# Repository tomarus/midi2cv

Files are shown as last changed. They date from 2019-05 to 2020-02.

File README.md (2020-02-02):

MIARPH * MIDI2CV + ARPEGGIATOR
==============================

Miarph is an Arduino based MIDI2CV converter with 4 0-5V 12 bit DAC's and 10 trigger outputs.

Preview 1.0 PCB

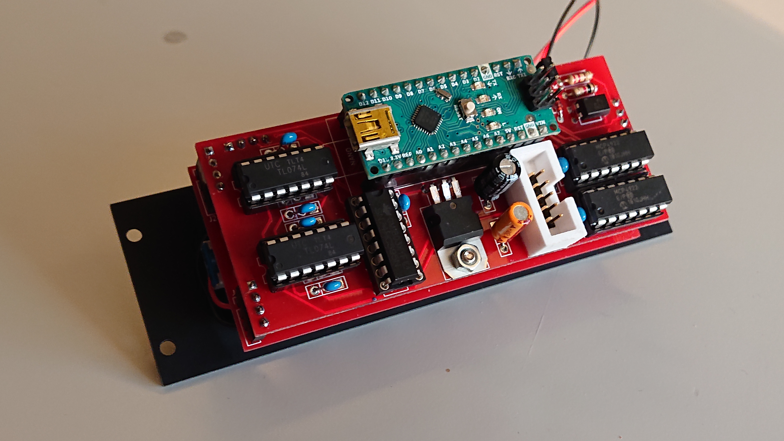
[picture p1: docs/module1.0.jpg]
Preview 1.0 Module


Video Demo (http://www.youtube.com/watch?v=SEof3n9Ys9w)

Video Demo (http://www.youtube.com/watch?v=0akh9hcQQY0)

## Features

* 4 individual 0-5v 12 bit DAC's (MCP4922 based)
* 10 Trigger outputs
* Dual Arpeggiator
* SYSEX configurable.
* Two MIDI-CC controller outputs.
* Two Midi Note + Trigger outputs.
* Split note (single channel) or two individual channel operations.
* 8 individually programmable gate triggers to be either drum trigger or clock divider.

## Building Notes

* Use a real Arduino Nano or atleast one with a real FTDI chip.
* There is no tuning possibility, but a stable LM7805 is key.
* The LED is on the wrong side but easy fixable using 2 short wires. (This is the only mistake on the PCB).
* The LED resistor is dependent on your LED specs.
* Capacitors have three holes, always use the square one and one of the others. Both 2.54mm and 5.08mm caps will fit.
* Polarized caps should have their positive in the square hole and the negative pointing outwards the board. (See image above!)
* Remove the jumper and power cable before programming!
* DO NOT CONNECT POWER AND USB AT THE SAME TIME!

## BUGS

* It crashes at split note change. But after a reset it is correctly read from eeprom.
* Transpose is buggy, but required because it can only support 60 MIDI notes.

## Programming Using Webconfig

See https://midi.tomarus.io/miarph/

You need a modern browser like Opera or Chrome to use this site.

Note that all values are initially *unknown* until you actually change something.
The device has no MIDI output so config values can't be read back.

After initially building the device, you should set all of your defaults once via webconfig.
After changing values it is stored on the device's eeprom and used at the next power up.

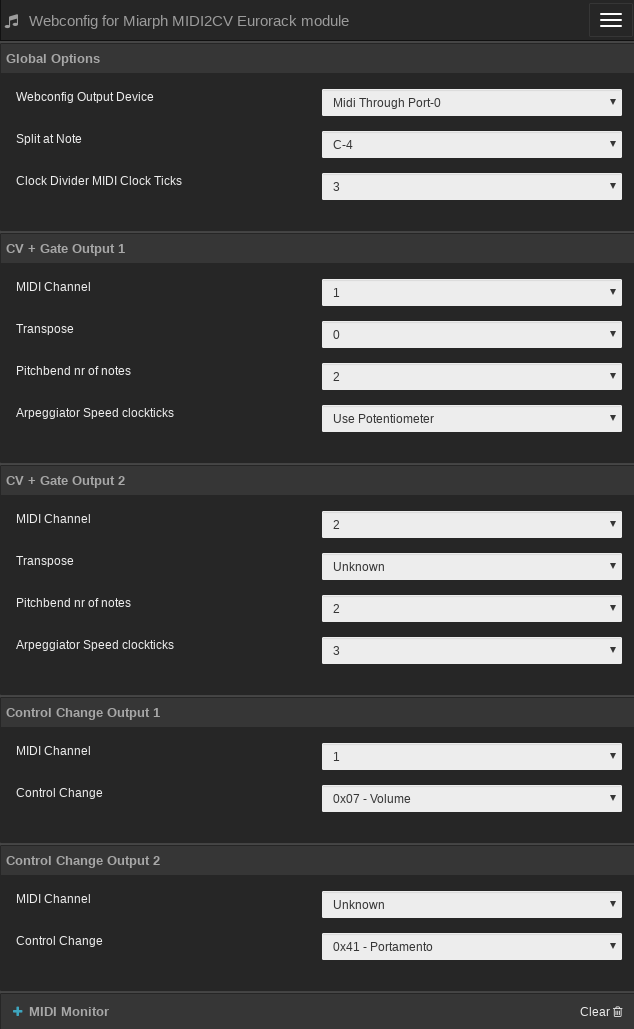
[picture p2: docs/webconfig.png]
Webconfig Screenshot


## Programming Using the Commandline

Use the ```midi2cv``` Go utility to program the device.

Example:

```./midi2cv write 0x01 0x77```

Where ```0x01``` is the address and ```0x77``` the value.

List of addresses to program:

| Address | Description | Example value |
| -- | -- | -- |
| 0x00 | unused | -- |
| 0x01 | Split keyboard at note | 0x40 (use 0x00 for no split) |
| 0x02 | MIDI 1 Channel | 0x01 |
| 0x03 | MIDI 2 Channel | 0x02 |
| 0x04 | Transpose Channel 1 | 0x40 |
| 0x05 | Transpose Channel 2 | 0x40 |
| 0x06 | Control Change Number Channel 1 | 0x07 (0x07 = volume) |
| 0x07 | Control Change Number Channel 2 | 0x6A (0x6A = filter cutoff) |
| 0x08 | Control Change Channel 1 | 0x01 |
| 0x09 | Control Change Channel 2 | 0x02 |
| 0x0a | Pitchbend Channel 1 | 0x02 (number of notes) |
| 0x0b | Pitchbend Channel 2 | 0x0c (number of notes) |
| 0x0c | Midi Channel 1 sync | 0x00 (00 = use potmeter, otherwise nr of midi clock ticks) |
| 0x0d | Midi Channel 2 sync | 0x00 (00 = use potmeter, otherwise nr of midi clock ticks) |
| 0x0e | Clockticks to advance the clock divider | 0x03 (0x03 = sync to quarter notes) |
| 0x0f | unused | -- |
| 0x10..0x18 | Port Mode (0 = clock divider, 1 = drum trigger) | 0x00 |
| 0x18..0x20 | Port Trigger Note | 0x36 |
| 0x20..0x28 | Port Clock Divider Division (0=1/1, 1=1/2, 2=1/4, 3=1/8, etc) | 0x00 |

## Bill Of Materials

|Designator                   |Package                                 |Quantity|Designation |PartNo|
|-----------------------------|----------------------------------------|--------|------------|------|
|RV1                          |Potentiometer_Alps_RK09K_Single_Vertical|1       |B10K        | |
|NANO                         |Arduino_Nano_Silk                       |1       |Nano v3     | |
|C1                           |GenericCap                              |1       |100uF       | |
|C2                           |GenericCap                              |1       |10uF        | |
|C3,C4,C5,C6,C7,C8,C9         |GenericCap                              |7       |100nF       | |
|D1                           |LED_D3.0mm                              |1       |LED         | |
|D2,D3,D4                     |D_DO-35_SOD27_P7.62mm_Horizontal        |3       |D           | |
|J1                           |PinHeader_1x02_P2.54mm_Vertical         |1       |ProgramJmpr | |
|J2                           |IDC-Header_2x05_P2.54mm_Vertical        |1       |Power       | |
|J3,J14,J15                   |PinSocket_1x04_P2.54mm_Vertical         |3       |Conn_01x04_M| |
|J4,J24,J25                   |PinHeader_1x04_P2.54mm_Vertical         |3       |Conn_01x04_F| |
|J5                           |PinSocket_1x08_P2.54mm_Vertical         |1       |Conn_01x08_M| |
|J6                           |PinHeader_1x08_P2.54mm_Vertical         |1       |Conn_01x08_F| |
|J7                           |Jack_3.5mm_QingPu_WQP-PJ366ST_Vertical  |1       |Midi Input  | |
|J8-J13,J16-J23               |Jack_3.5mm_QingPu_WQP-PJ398SM_Vertical  |14      |Misc        | |
|R1,R2                        |R_Axial_DIN0207_L6.3mm_D2.5mm_P7.62mm   |2       |2K2         | |
|R3,R4,R5,R6                  |R_Axial_DIN0207_L6.3mm_D2.5mm_P7.62mm   |4       |1K          | |
|R7                           |R_Axial_DIN0207_L6.3mm_D2.5mm_P7.62mm   |1       |220         | |
|R8,R9,R10,R11,R12,R13,R14,R15|R_Axial_DIN0207_L6.3mm_D2.5mm_P7.62mm   |8       |100         | |
|U1                           |TO-220-3_Horizontal_TabDown             |1       |L7805       | |
|U2                           |DIP-8_W7.62mm                           |1       |24LC256     | |
|U5                           |DIP-4_W7.62mm                           |1       |PC817       | PC817XNNSZ1B |
|U6,U8                        |DIP-14_W7.62mm                          |2       |TL074       | |
|U7                           |DIP-16_W7.62mm                          |1       |74HC595     | |
|U3,U4                        |DIP-14_W7.62mm                          |2       |MCP4922     | |

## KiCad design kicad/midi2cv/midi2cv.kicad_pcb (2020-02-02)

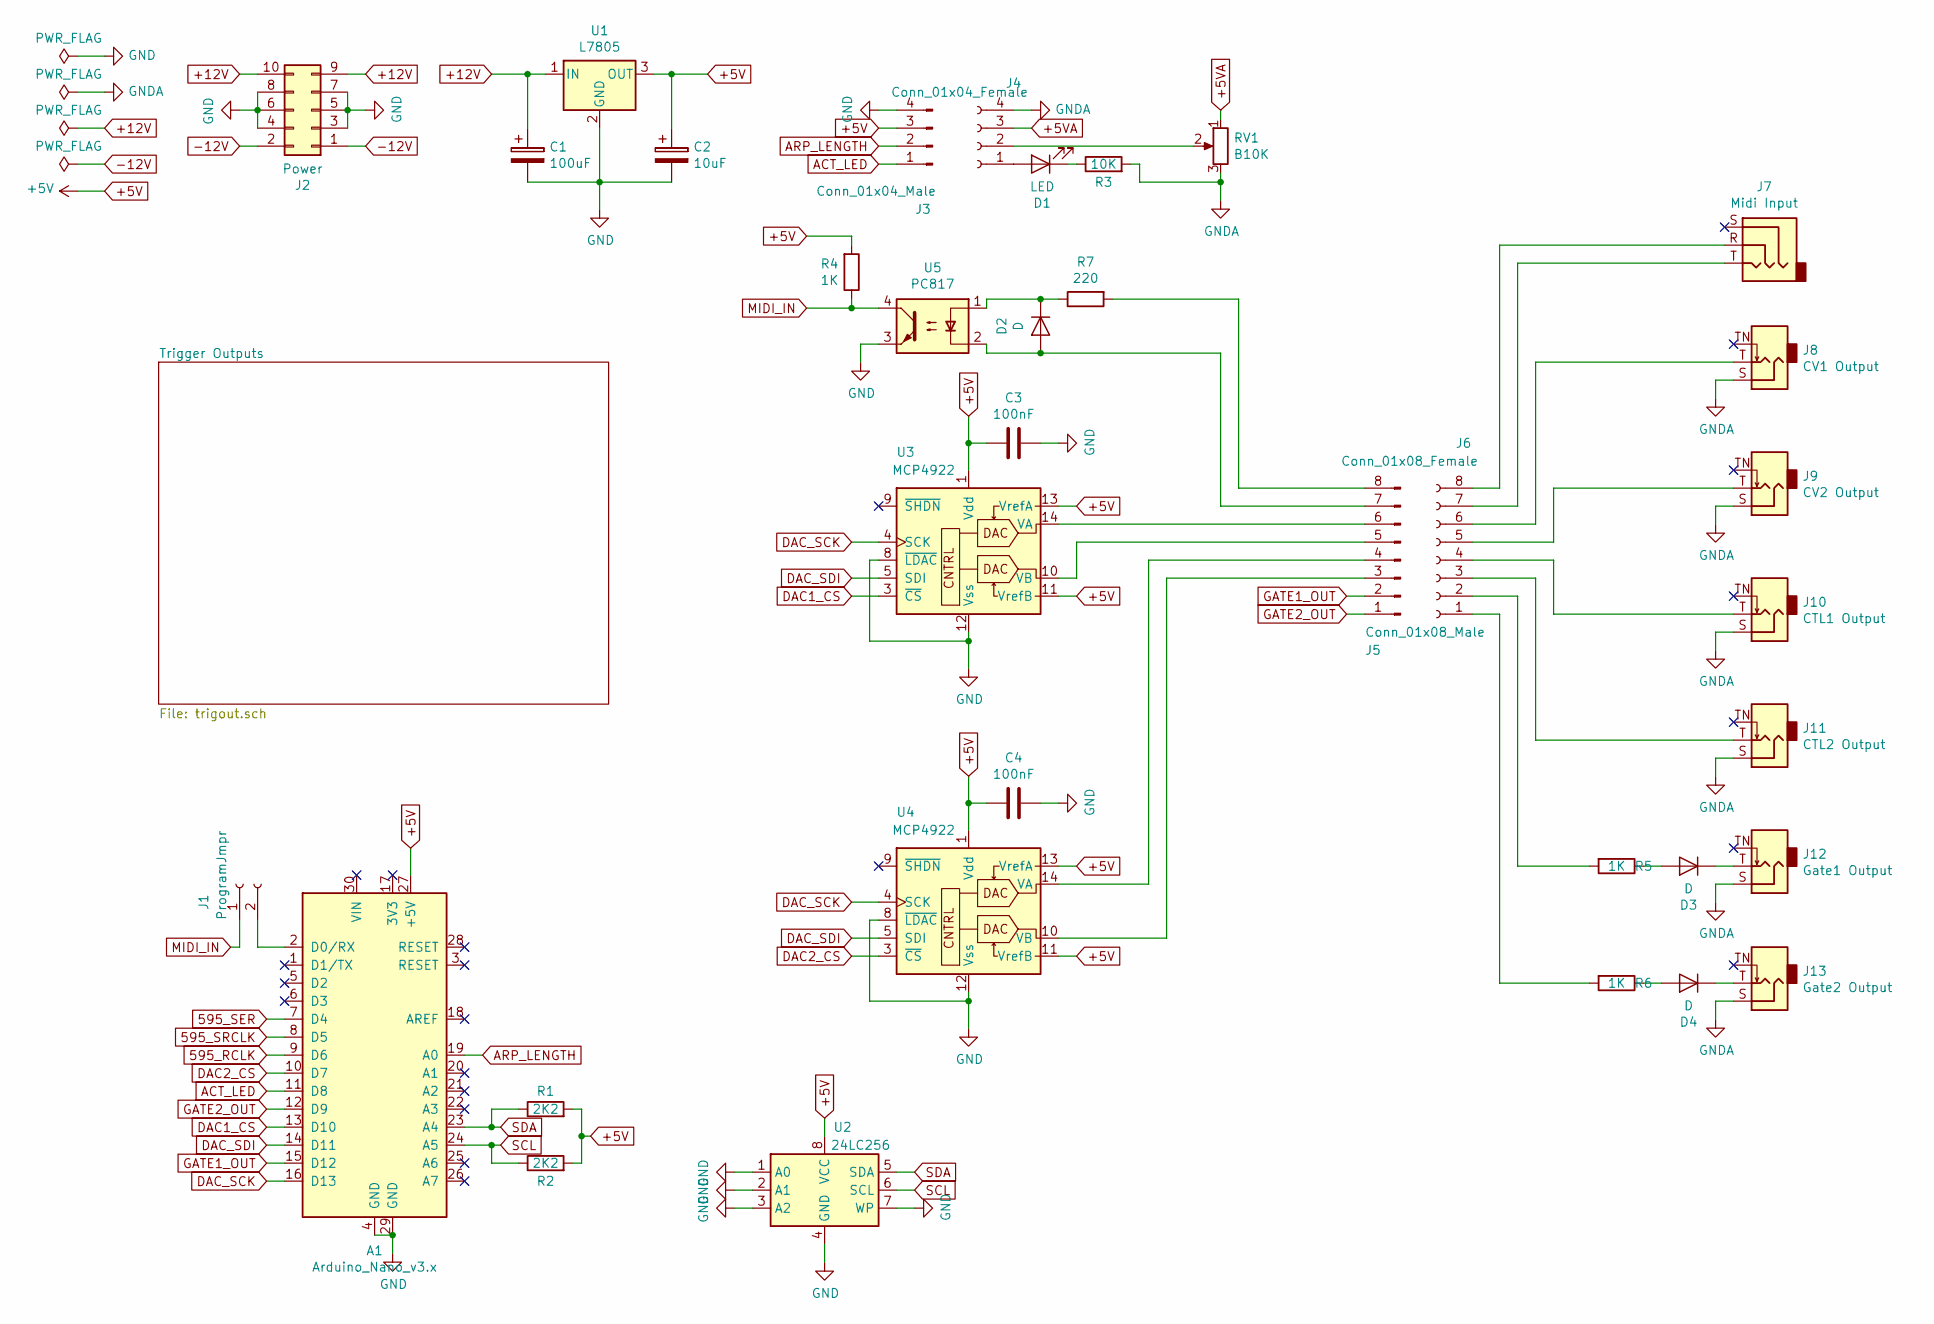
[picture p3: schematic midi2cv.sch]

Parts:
A1: Arduino_Nano_v3.x; Arduino_Nano_Silk
C1: 100uF; GenericCap
C2: 10uF; GenericCap
C3, C4: 100nF; GenericCap
D1: LED; LED_D3.0mm
D2, D3, D4: D; D_DO-35_SOD27_P7.62mm_Horizontal
J1: ProgramJmpr; PinHeader_1x02_P2.54mm_Vertical
J2: Power; IDC-Header_2x05_P2.54mm_Vertical
J3: Conn_01x04_Male; PinSocket_1x04_P2.54mm_Vertical
J4: Conn_01x04_Female; PinHeader_1x04_P2.54mm_Vertical
J5: Conn_01x08_Male; PinSocket_1x08_P2.54mm_Vertical
J6: Conn_01x08_Female; PinHeader_1x08_P2.54mm_Vertical
J7: Midi Input; Jack_3.5mm_QingPu_WQP-PJ366ST_Vertical_CircularHoles
J8: CV1 Output; Jack_3.5mm_QingPu_WQP-PJ398SM_Vertical_CircularHoles
J9: CV2 Output; Jack_3.5mm_QingPu_WQP-PJ398SM_Vertical_CircularHoles
J10: CTL1 Output; Jack_3.5mm_QingPu_WQP-PJ398SM_Vertical_CircularHoles
J11: CTL2 Output; Jack_3.5mm_QingPu_WQP-PJ398SM_Vertical_CircularHoles
J12: Gate1 Output; Jack_3.5mm_QingPu_WQP-PJ398SM_Vertical_CircularHoles
J13: Gate2 Output; Jack_3.5mm_QingPu_WQP-PJ398SM_Vertical_CircularHoles
R1, R2: 2K2; R_Axial_DIN0207_L6.3mm_D2.5mm_P7.62mm_Horizontal
R3: 10K; R_Axial_DIN0207_L6.3mm_D2.5mm_P7.62mm_Horizontal
R4, R5, R6: 1K; R_Axial_DIN0207_L6.3mm_D2.5mm_P7.62mm_Horizontal
R7: 220; R_Axial_DIN0207_L6.3mm_D2.5mm_P7.62mm_Horizontal
RV1: B10K; Potentiometer_Alps_RK09K_Single_Vertical
U1: L7805; TO-220-3_Horizontal_TabDown
U2: 24LC256; DIP-8_W7.62mm
U3, U4: MCP4922; DIP-14_W7.62mm
U5: PC817; DIP-4_W7.62mm

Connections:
595_RCLK: A1.9 (D6); also elsewhere on the board
595_SER: A1.7 (D4); also elsewhere on the board
595_SRCLK: A1.8 (D5); also elsewhere on the board
+5V: A1.27 (+5V), C2.1, C3.1, C4.1, J3.3, R1.2, R2.2, R4.2, U1.3 (OUT), U2.8 (VCC), U3.1 (Vdd), U3.11 (VrefB), U3.13 (VrefA), U4.1 (Vdd), U4.11 (VrefB), U4.13 (VrefA); also elsewhere on the board
+5VA: J4.3, RV1.1
+12V: C1.1, J2.9, J2.10, U1.1 (IN); also elsewhere on the board
-12V: J2.1, J2.2; also elsewhere on the board
ACT_LED: A1.11 (D8), J3.1
ARP_LENGTH: A1.19 (A0), J3.2
DAC1_CS: A1.13 (D10), U3.3 (~CS)
DAC2_CS: A1.10 (D7), U4.3 (~CS)
DAC_SCK: A1.16 (D13), U3.4 (SCK), U4.4 (SCK)
DAC_SDI: A1.14 (D11), U3.5 (SDI), U4.5 (SDI)
GATE1_OUT: A1.15 (D12), J5.2
GATE2_OUT: A1.12 (D9), J5.1
GND: A1.4 (GND), A1.29 (GND), C1.2, C2.2, C3.2, C4.2, J2.3, J2.4, J2.5, J2.6, J2.7, J2.8, J3.4, U1.2 (GND), U2.1 (A0), U2.2 (A1), U2.3 (A2), U2.4 (GND), U2.7 (WP), U3.8 (~LDAC), U3.12 (Vss), U4.8 (~LDAC), U4.12 (Vss), U5.3; also elsewhere on the board
GNDA: J4.4, J8.S, J9.S, J10.S, J11.S, J12.S, J13.S, R3.2, RV1.3; also elsewhere on the board
MIDI_IN: J1.1, R4.1, U5.4
unnamed: A1.2 (D0/RX), J1.2
unnamed: D1.1 (K), R3.1
unnamed: D1.2 (A), J4.1
unnamed: D2.1 (K), R7.1, U5.1
unnamed: D2.2 (A), J5.7, U5.2
unnamed: D3.1 (K), J12.T
unnamed: D3.2 (A), R5.1
unnamed: D4.1 (K), J13.T
unnamed: D4.2 (A), R6.1
unnamed: J4.2, RV1.2
unnamed: J5.3, U4.10 (VB)
unnamed: J5.4, U4.14 (VA)
unnamed: J5.5, U3.10 (VB)
unnamed: J5.6, U3.14 (VA)
unnamed: J5.8, R7.2
unnamed: J6.1, R6.2
unnamed: J6.2, R5.2
unnamed: J6.5, J9.T
unnamed: J6.6, J8.T
unnamed: J6.7, J7.T
unnamed: J6.8, J7.R
unnamed: J6.4, J10.T
unnamed: J6.3, J11.T
SCL: A1.24 (A5), R2.1, U2.6 (SCL)
SDA: A1.23 (A4), R1.1, U2.5 (SDA)

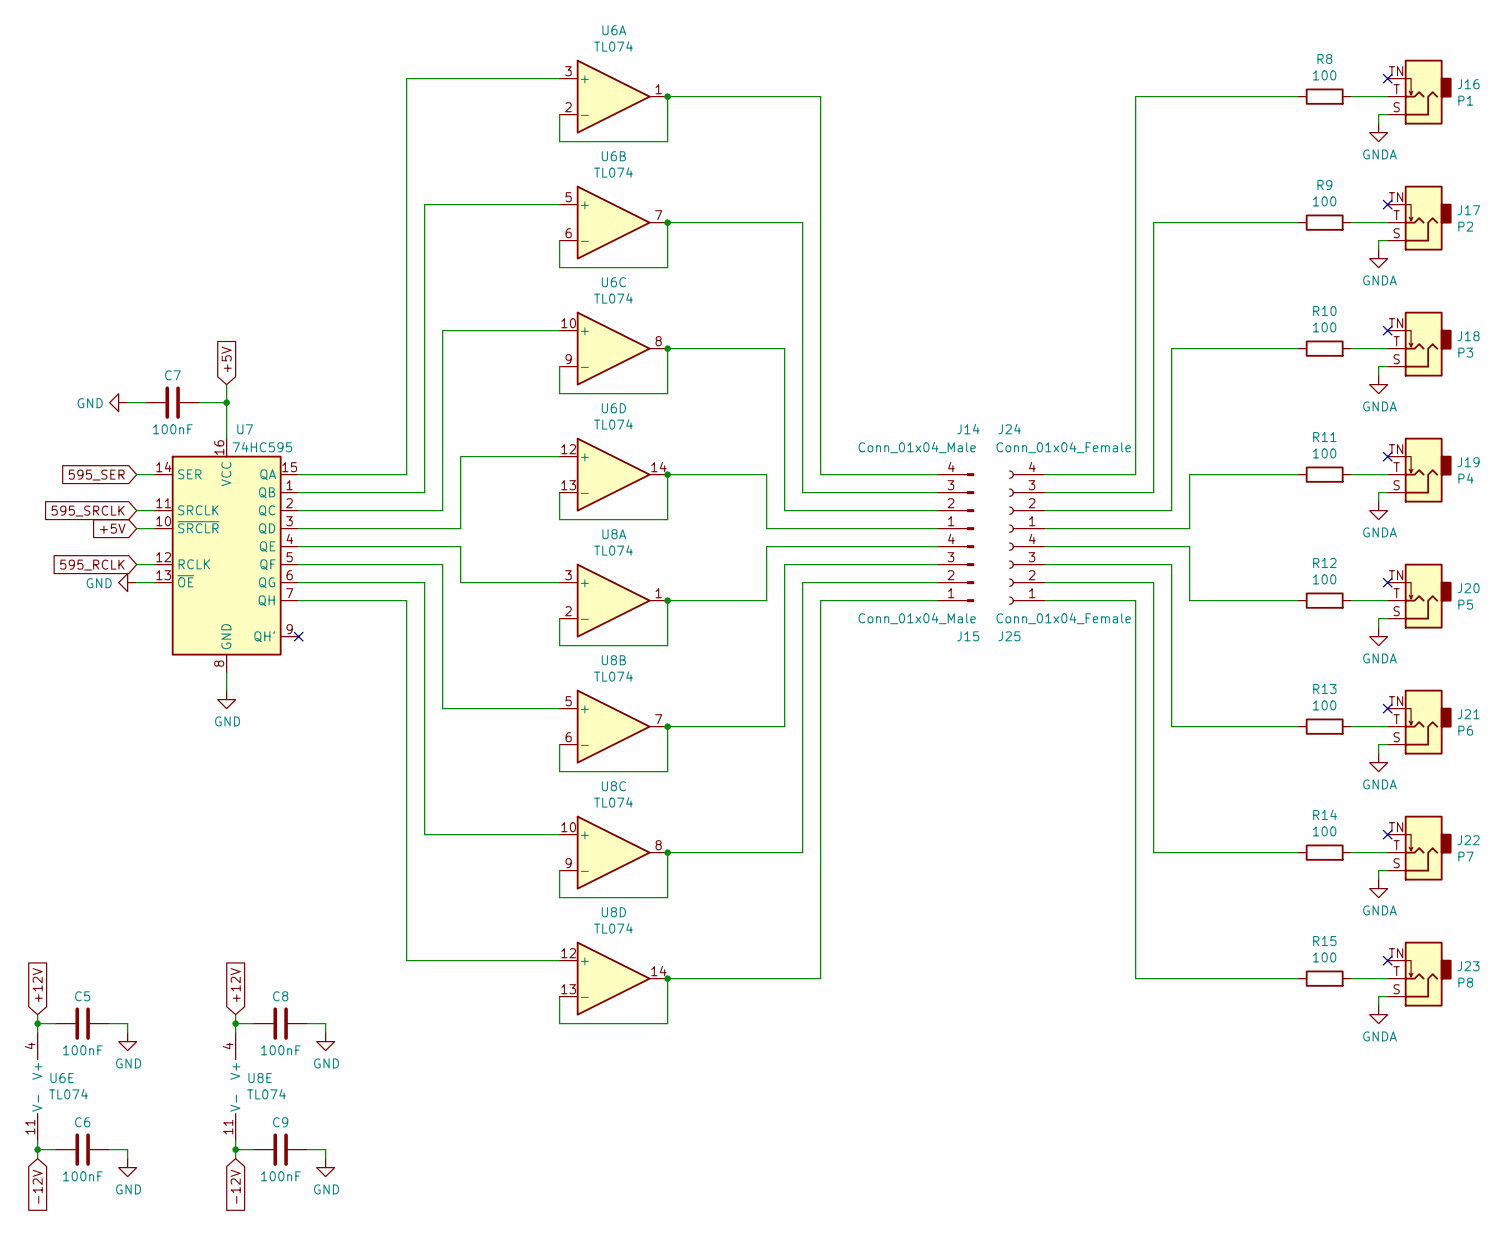
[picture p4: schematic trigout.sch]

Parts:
C5, C6, C7, C8, C9: 100nF; GenericCap
J14, J15: Conn_01x04_Male; PinSocket_1x04_P2.54mm_Vertical
J16: P1; Jack_3.5mm_QingPu_WQP-PJ398SM_Vertical_CircularHoles
J17: P2; Jack_3.5mm_QingPu_WQP-PJ398SM_Vertical_CircularHoles
J18: P3; Jack_3.5mm_QingPu_WQP-PJ398SM_Vertical_CircularHoles
J19: P4; Jack_3.5mm_QingPu_WQP-PJ398SM_Vertical_CircularHoles
J20: P5; Jack_3.5mm_QingPu_WQP-PJ398SM_Vertical_CircularHoles
J21: P6; Jack_3.5mm_QingPu_WQP-PJ398SM_Vertical_CircularHoles
J22: P7; Jack_3.5mm_QingPu_WQP-PJ398SM_Vertical_CircularHoles
J23: P8; Jack_3.5mm_QingPu_WQP-PJ398SM_Vertical_CircularHoles
J24, J25: Conn_01x04_Female; PinHeader_1x04_P2.54mm_Vertical
R8, R9, R10, R11, R12, R13, R14, R15: 100; R_Axial_DIN0207_L6.3mm_D2.5mm_P7.62mm_Horizontal
U6, U8: TL074; DIP-14_W7.62mm
U7: 74HC595; DIP-16_W7.62mm

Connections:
595_RCLK: U7.12 (RCLK); also elsewhere on the board
595_SER: U7.14 (SER); also elsewhere on the board
595_SRCLK: U7.11 (SRCLK); also elsewhere on the board
+5V: C7.1, U7.10 (~SRCLR), U7.16 (VCC); also elsewhere on the board
+12V: C5.2, C8.2, U6.4 (V+), U8.4 (V+); also elsewhere on the board
-12V: C6.2, C9.2, U6.11 (V-), U8.11 (V-); also elsewhere on the board
GND: C5.1, C6.1, C7.2, C8.1, C9.1, U7.8 (GND), U7.13 (~OE); also elsewhere on the board
GNDA: J16.S, J17.S, J18.S, J19.S, J20.S, J21.S, J22.S, J23.S; also elsewhere on the board
unnamed: J14.1, U6.13 (-), U6.14
unnamed: J14.2, U6.8, U6.9 (-)
unnamed: J14.3, U6.6 (-), U6.7
unnamed: J14.4, U6.1, U6.2 (-)
unnamed: J15.1, U8.13 (-), U8.14
unnamed: J15.2, U8.8, U8.9 (-)
unnamed: J15.3, U8.6 (-), U8.7
unnamed: J15.4, U8.1, U8.2 (-)
unnamed: J16.T, R8.2
unnamed: J17.T, R9.2
unnamed: J18.T, R10.2
unnamed: J19.T, R11.2
unnamed: J20.T, R12.2
unnamed: J21.T, R13.2
unnamed: J22.T, R14.2
unnamed: J23.T, R15.2
unnamed: J24.1, R11.1
unnamed: J24.2, R10.1
unnamed: J24.3, R9.1
unnamed: J24.4, R8.1
unnamed: J25.1, R15.1
unnamed: J25.2, R14.1
unnamed: J25.3, R13.1
unnamed: J25.4, R12.1
unnamed: U6.3 (+), U7.15 (QA)
unnamed: U6.5 (+), U7.1 (QB)
unnamed: U6.10 (+), U7.2 (QC)
unnamed: U6.12 (+), U7.3 (QD)
unnamed: U7.4 (QE), U8.3 (+)
unnamed: U7.5 (QF), U8.5 (+)
unnamed: U7.6 (QG), U8.10 (+)
unnamed: U7.7 (QH), U8.12 (+)

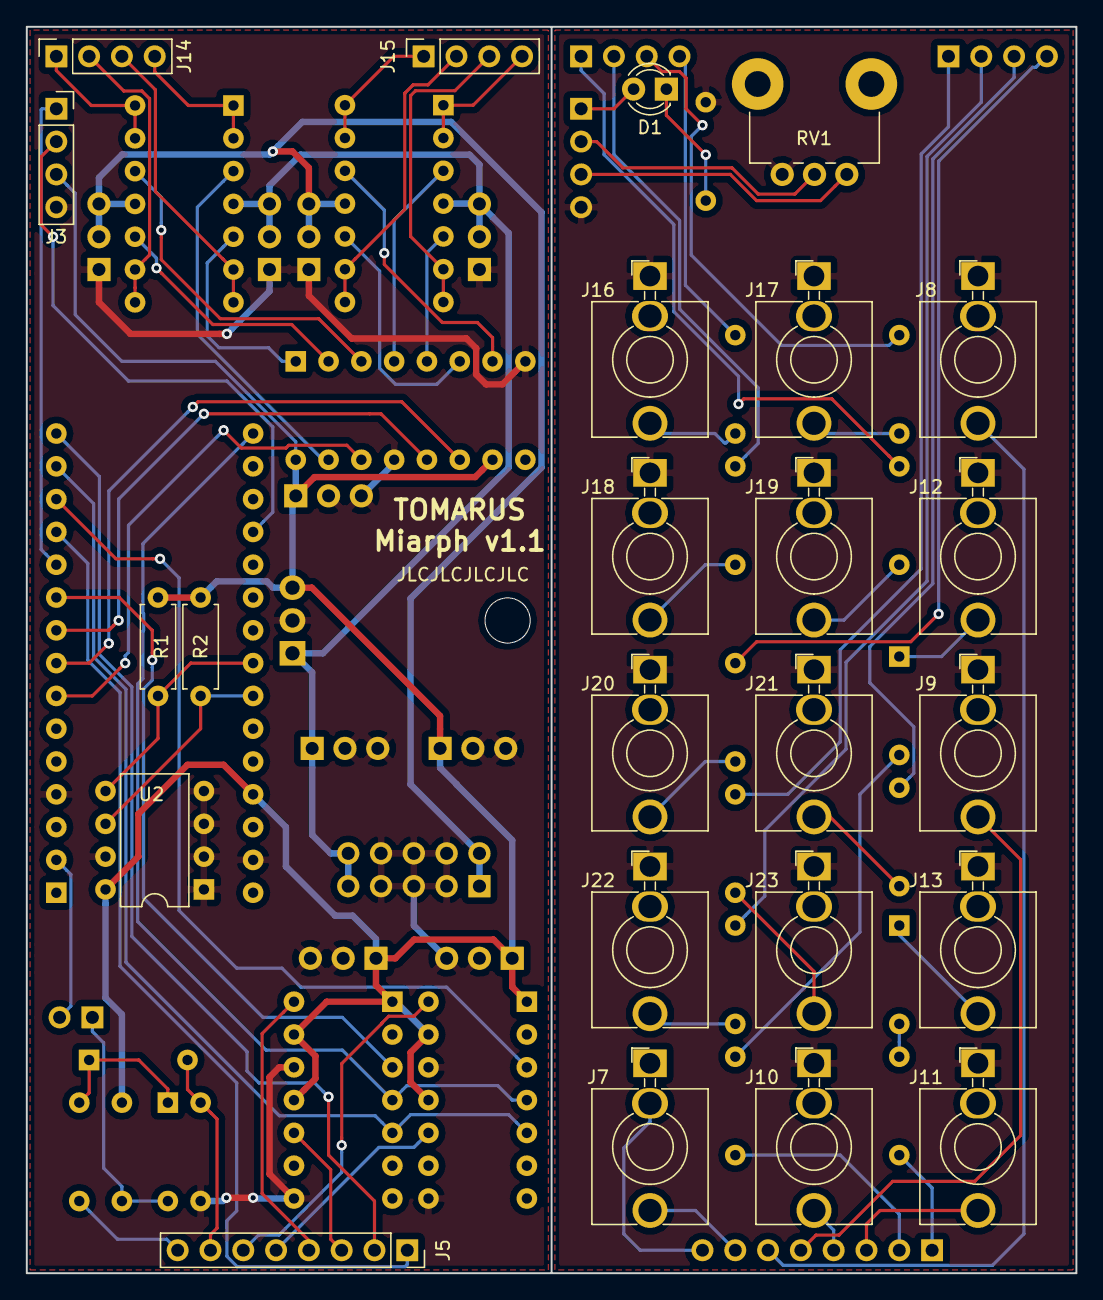
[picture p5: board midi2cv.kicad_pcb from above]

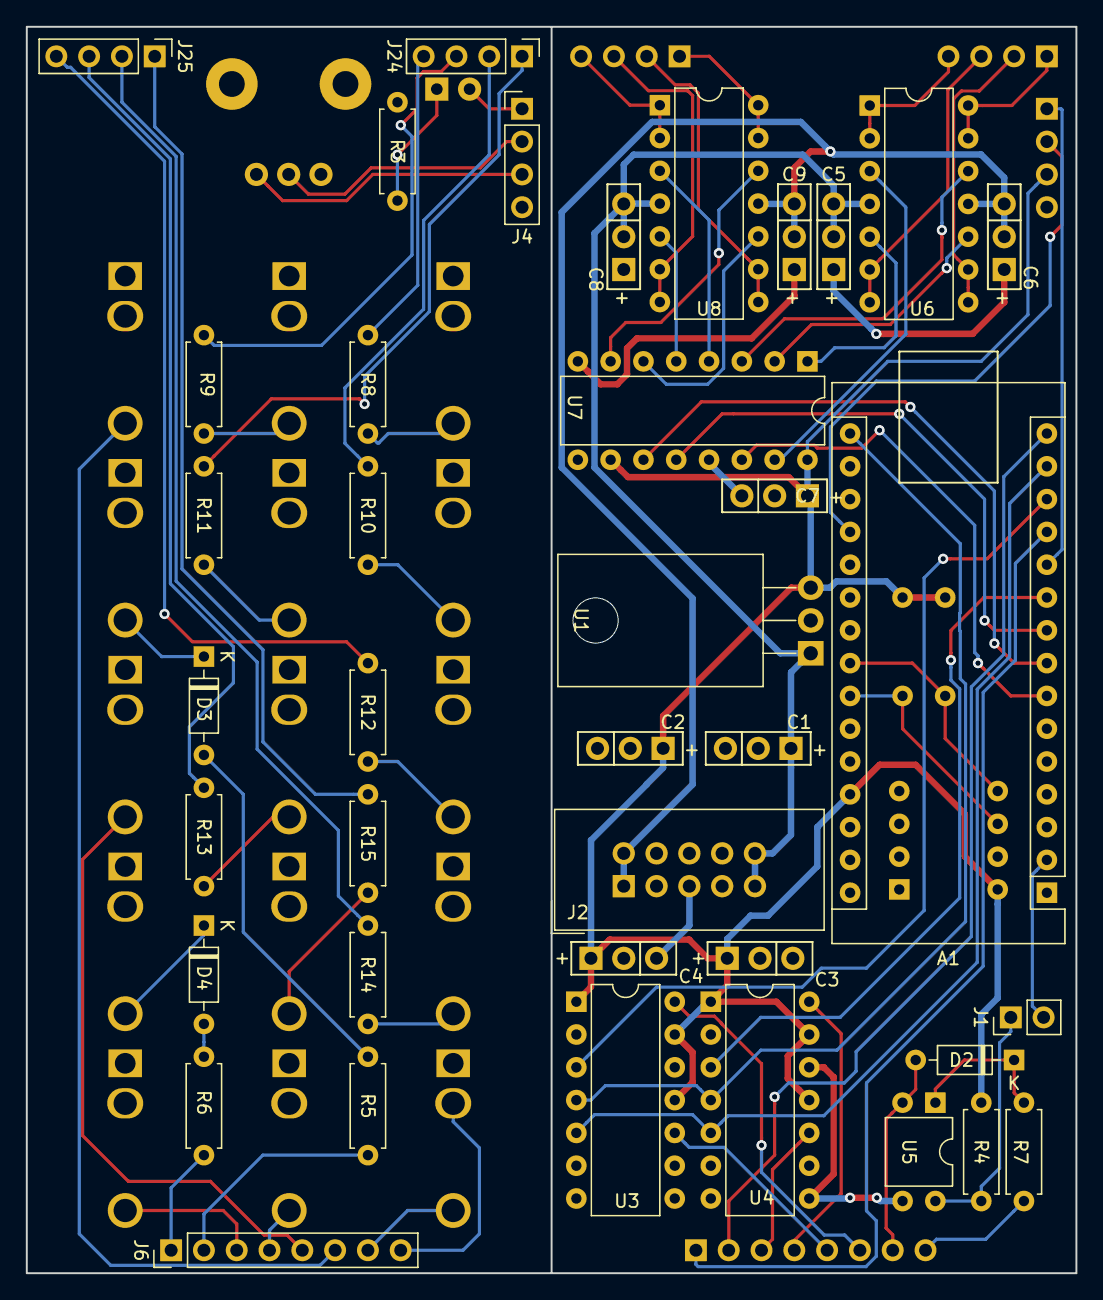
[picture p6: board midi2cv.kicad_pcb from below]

Board: 2 copper layers, 81.3 x 96.5 mm, 63 parts (39 on the bottom side), 75 nets.

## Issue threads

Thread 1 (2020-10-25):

Just a few questions please !

pierstu, 2020-10-25:
Hello, I'm planning to build a run of this module for me and a mate, and it looks like it has most of the functions i was waiting for, thank you for making it free and open.

I have just a few questions :

- What kind of diodes should be used at D2 to D4? My guess is low voltage schottkys, but i'd love to have a confirmation please.
- What are the two wires on the top left of the second picture on the readme connected to, please? It looks like the right side of the picture corresponds to the bottom side of the module, so they begin at the midi trs cable,
- What minimal Go setup would you recommend to program the module via CL? Is it ok to throw sysex messages via a dedicated program (MidiOx, gMidimonitor, ...) if you ever tried it?
- if i understand properly, one would be able to send the midi clock to one or several trigger outputs when properly configured? (Just to make _real_ sure)

Thank you, hope everything is ok, have a nice evening !

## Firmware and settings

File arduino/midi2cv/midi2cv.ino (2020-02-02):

#include <SPI.h>
#include <DAC_MCP49xx.h>
#include <MIDI.h>

#include "eeprom.h"
#include "arp.h"

#define PIN_595_SER 4
#define PIN_595_SRCLK 5
#define PIN_595_RCLK 6
#define PIN_DAC2_CS 7
#define PIN_LED 8
#define PIN_GATE2 9
#define PIN_DAC1_CS 10
#define PIN_GATE1 12
#define PIN_POT_SPEED A0

// Only change this if you have more than one Miarph
#define MIARPH_DEVICE_ID 0x4f

MIDI_CREATE_DEFAULT_INSTANCE();

Config cfg(0x50); // I2C addr of 24LC256

DAC_MCP49xx dac1(DAC_MCP49xx::MCP4922, PIN_DAC1_CS); // DAC model, CS pin, LDAC pin
DAC_MCP49xx dac2(DAC_MCP49xx::MCP4922, PIN_DAC2_CS); // DAC model, CS pin, LDAC pin

Arp arp1;
Arp arp2;

void setup()
{
	pinMode(PIN_595_SER, OUTPUT);
	pinMode(PIN_595_SRCLK, OUTPUT);
	pinMode(PIN_595_RCLK, OUTPUT);

	pinMode(PIN_DAC1_CS, OUTPUT);
	pinMode(PIN_DAC2_CS, OUTPUT);

	pinMode(PIN_LED, OUTPUT);
	pinMode(PIN_GATE1, OUTPUT);
	pinMode(PIN_GATE2, OUTPUT);

	digitalWrite(PIN_LED, true);
	digitalWrite(PIN_GATE1, false);
	digitalWrite(PIN_GATE2, false);

	cfg.Load();
	arp1.Transpose = cfg.mem.transpose1;
	arp2.Transpose = cfg.mem.transpose2;
	arp1.Pitch = 0;
	arp2.Pitch = 0;

	dac1.setSPIDivider(SPI_CLOCK_DIV2);
	dac1.setAutomaticallyLatchDual(false);
	dac1.setPortWrite(true);

	dac2.setSPIDivider(SPI_CLOCK_DIV2);
	dac2.setAutomaticallyLatchDual(false);
	dac2.setPortWrite(false); // false cos non standard spi port

	dac1.output2(0, 0);
	dac2.output2(0, 0);

	MIDI.begin(0); // channel
	MIDI.setHandleClock(handleClock);
	MIDI.setHandleNoteOn(handleNoteOn);
	MIDI.setHandleNoteOff(handleNoteOff);
	MIDI.setHandleControlChange(handleControl);
	MIDI.setHandleStop(handleStop);
	MIDI.setHandleStart(handleStart);
	MIDI.setHandleSystemExclusive(handleSysex);
	MIDI.setHandlePitchBend(handlePitchBend);
}

bool onoff;
void toggleled()
{
	onoff = !onoff;
	digitalWrite(PIN_LED, onoff);
}

void loop()
{
	MIDI.read();

	int speed = analogRead(PIN_POT_SPEED);
	if (cfg.mem.midi1sync == 0)
	{
		int val = arp1.CheckPlayNote(speed);
		if (val != -1)
			dac1.outputA(val);
	}
	if (cfg.mem.midi2sync == 0)
	{
		int val = arp2.CheckPlayNote(speed);
		if (val != -1)
			dac1.outputB(val);
	}
}

byte shiftreg = 0;

void handleNoteOn(byte chan, byte note, byte vel)
{
	if (chan == cfg.mem.midi1 && cfg.mem.split > 0)
	{
		if (note >= cfg.mem.split)
		{
			int val = arp1.HandleNoteOn(note);
			if (val != -1)
			{
				digitalWrite(PIN_GATE1, true);
				dac1.outputA(val);
			}
		}
		if (note < cfg.mem.split)
		{
			int val = arp2.HandleNoteOn(note);
			if (val != -1)
			{
				digitalWrite(PIN_GATE2, true);
				dac1.outputB(val);
			}
		}
		return;
	}

	if (chan == cfg.mem.midi1)
	{
		int val = arp1.HandleNoteOn(note);
		if (val != -1)
		{
			digitalWrite(PIN_GATE1, true);
			dac1.outputA(val);
			return;
		}
	}

	if (chan == cfg.mem.midi2)
	{
		int val = arp2.HandleNoteOn(note);
		if (val != -1)
		{
			digitalWrite(PIN_GATE2, true);
			dac1.outputB(val);
		}
	}

	bool triggered = false;
	for (int i = 0; i < 8; i++)
	{
		if (cfg.mem.pmode[i] == 1 && note == cfg.mem.pnote[i]) {
			shiftreg = shiftreg ^ 1 << i;
			triggered = true;
		}
	}
	if (triggered) {
		shiftOut(PIN_595_SER, PIN_595_SRCLK, PIN_595_RCLK, shiftreg);
	}
}

void handleNoteOff(byte chan, byte note, byte vel)
{
	if (chan == cfg.mem.midi1 && cfg.mem.split > 0)
	{
		if (note >= cfg.mem.split)
		{
			bool gate = arp1.HandleNoteOff(note);
			if (gate)
				digitalWrite(PIN_GATE1, false);
		}
		if (note < cfg.mem.split)
		{
			bool gate = arp2.HandleNoteOff(note);
			if (gate)
				digitalWrite(PIN_GATE2, false);
		}
		return;
	}

	if (chan == cfg.mem.midi1)
	{
		bool gate = arp1.HandleNoteOff(note);
		if (gate)
		{
			digitalWrite(PIN_GATE1, false);
			return;
		}
	}

	if (chan == cfg.mem.midi2)
	{
		bool gate = arp2.HandleNoteOff(note);
		if (gate)
		{
			digitalWrite(PIN_GATE2, false);
		}
	}

	bool triggered = false;
	for (int i = 0; i < 8; i++)
	{
		if (cfg.mem.pmode[i] == 1 && note == cfg.mem.pnote[i]) {
			shiftreg = shiftreg & ~(1 << i);
			triggered = true;
		}
	}
	if (triggered) {
		shiftOut(PIN_595_SER, PIN_595_SRCLK, PIN_595_RCLK, shiftreg);
	}
}

// handle sustain pedal
void handleControl(byte chan, byte cc, byte val)
{
	if (cc == cfg.mem.cc1 && chan == cfg.mem.cc1ch)
	{
		dac2.outputA(val * 32);
		return;
	}

	if (cc == cfg.mem.cc2 && chan == cfg.mem.cc2ch)
	{
		dac2.outputB(val * 32);
		return;
	}
}

void handleStop()
{
	// maxpnote = 0;
	// maxnote = 0;
	// curnote = 0;
}

static void handleSysex(byte *array, unsigned size)
{
	if (size < 5)
		return;
	if (!(array[1] == 0x7d && array[2] == 0x2a && array[3] == MIARPH_DEVICE_ID))
		return;

	for (int i = 4; i < size - 1; i++)
	{
		int command = array[i];
		if (command >= 0x40)
		{
			return;
		}

		switch (command)
		{
		case 1: // cmd 0x01 = write a config byte
		{
			cfg.Write(array[i + 1], array[i + 2]); // addr = byte1, val = byte2
			if (array[i + 1] == 0x04)
			{
				arp1.Transpose = array[i + 2];
			}
			if (array[i + 1] == 0x05)
			{
				arp2.Transpose = array[i + 2];
			}
			break;
		}
		}
	}
}

int ticks = 0;
int midi1ticks = 0;
int midi2ticks = 0;
byte clock = 0xff;
byte oldclock = 0xff;

void handleStart()
{
	ticks = cfg.mem.clockticks - 1;
	midi1ticks = cfg.mem.midi1sync;
	midi2ticks = cfg.mem.midi2sync;
	clock = 0xff;
	oldclock = 0xff;
	arp1.Reset();
	arp2.Reset();
}

void handleClock(void)
{
	midi1ticks++;
	if (cfg.mem.midi1sync > 0 && midi1ticks >= cfg.mem.midi1sync)
	{
		midi1ticks = 0;
		int val = arp1.PlayNote();
		if (val != -1)
		{
			dac1.outputA(val);
		}
	}

	midi2ticks++;
	if (cfg.mem.midi2sync > 0 && midi2ticks >= cfg.mem.midi2sync)
	{
		midi2ticks = 0;
		int val = arp2.PlayNote();
		if (val != -1)
		{
			dac1.outputB(val);
		}
	}

	ticks++;
	if (ticks >= cfg.mem.clockticks)
	{
		toggleled();
		ticks = 0;
		clock++;
		byte val = oldclock ^ clock;
		oldclock = clock;
		for (int i = 0; i < 8; i++) {
			if (cfg.mem.pmode[i] == 0) {
				if (val & 1 << (cfg.mem.pclock[i]+1)) {
					shiftreg = shiftreg ^ 1 << i;
				} else {
					shiftreg = shiftreg & ~(1 << i);
				}
			}
		}
	}
	shiftOut(PIN_595_SER, PIN_595_SRCLK, PIN_595_RCLK, shiftreg);
}

// shiftOut sets the 8 programmable gates to the
// individual bits of the data byte input.
void shiftOut(int ser, int srclk, int rclk, byte data)
{
	digitalWrite(rclk, 0);
	for (int i = 7; i >= 0; i--)
	{
		digitalWrite(srclk, 0);
		digitalWrite(ser, data & (1 << i));
		digitalWrite(srclk, 1);
	}
	digitalWrite(rclk, 1);
}

void handlePitchBend(byte chan, int val)
{
	if (cfg.mem.split > 0)
	{
		arp1.Pitch = (val / (16384 / (4096 / 60)) * cfg.mem.pb1range);
		arp2.Pitch = (val / (16384 / (4096 / 60)) * cfg.mem.pb2range);
		return;
	}

	if (chan == cfg.mem.midi1)
	{
		arp1.Pitch = (val / (16384 / (4096 / 60)) * cfg.mem.pb1range);
	}

	if (chan == cfg.mem.midi2)
	{
		arp2.Pitch = (val / (16384 / (4096 / 60)) * cfg.mem.pb2range);
	}
}

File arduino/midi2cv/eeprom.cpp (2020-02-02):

#include <Wire.h>
#include "eeprom.h"

Config::Config(byte addr)
{
	Wire.begin();
	this->devaddr = addr;
}

void Config::Load()
{
	byte *s = (byte *)this;
	for (int i = 0; i < sizeof(this->mem); i++)
	{
		*s++ = this->readAddr(i);
	}
}

void Config::Write(int addr, byte val)
{
	this->writeAddr(addr, val);
	this->setmem(addr, val);
}

byte Config::Len()
{
	return sizeof(this->mem);
}

//

void Config::setmem(int addr, byte val)
{
	// hacketyhack
	byte *s = (byte *)this;
	s += addr;
	*s = val;
}

void Config::writeAll()
{
	const byte *s = (const byte *)this;
	for (int i = 0; i < sizeof(this->mem); i++)
	{
		this->writeAddr(i, *s++);
	}
}

void Config::writeAddr(unsigned int addr, byte data)
{
	Wire.beginTransmission(this->devaddr);
	Wire.write((int)(addr >> 8));
	Wire.write((int)(addr & 0xFF));
	Wire.write(data);
	Wire.endTransmission();
	delay(10);
}

byte Config::readAddr(unsigned int addr)
{
	Wire.beginTransmission(this->devaddr);
	Wire.write((int)(addr >> 8));
	Wire.write((int)(addr & 0xFF));
	Wire.endTransmission();
	Wire.requestFrom(this->devaddr, 1);

	byte r = 0xaa;
	if (Wire.available())
		r = Wire.read();
	delay(10);
	return r;
}

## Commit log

2019-05-20 Initial commit.
    [clock.sch, midi2cv.kicad_pcb, midi2cv.sch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]
2019-05-23 Create pcb.
    [midi2cv.kicad_pcb, trigout.sch]
2019-05-23 Add frontpanel.
    [midi2cv.kicad_pcb]
2019-05-23 Add frontpanel kicad project.
    [frontpanel.kicad_pcb, frontpanel.sch]
2019-05-23 Update frontpanel.
    [frontpanel.kicad_pcb]
2019-05-23 Remove bak files.
    [clock.sch]
2019-05-24 Update some symbols + footprints.
    [frontpanel.kicad_pcb, midi2cv.kicad_pcb, midi2cv.sch]
2019-05-24 Small production updates.
    [frontpanel.kicad_pcb, midi2cv.kicad_pcb]
2019-05-24 Fix a gnd connection.
    [midi2cv.kicad_pcb]
2019-05-24 Production 1.0
    [frontpanel-B.Cu.gbr, frontpanel-B.Mask.gbr, frontpanel-B.SilkS.gbr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]
2019-06-08 More test code.
    [midi2cv.kicad_pcb, midi2cv.sch]
2019-06-09 Update code a bit, use config, fix some bugs.
    [eeprom.cpp, midi2cv.ino]
2019-06-10 Fix some bugs and remove some old code.
    [midi2cv.ino]
2019-06-26 Fix caps silkscreen + powerconnector.
    [midi2cv.kicad_pcb, midi2cv.sch]
2019-07-07 Add more documentation and the BOM.
2019-07-07 Optimize BOM table a bit.
2020-02-02 Make trigger ports configurable as either drum trigger or clock divider.
    [midi2cv.kicad_pcb, midi2cv.sch]
